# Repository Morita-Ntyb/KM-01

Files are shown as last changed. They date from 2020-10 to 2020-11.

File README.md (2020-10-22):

# KM-01
ミミがうごくヘッドホン

一つのミミにつきサーボ2つ(2軸) ヨーとピッチ方向で左右合計4軸を制御  
IMU(加速度センサ)の値を読み取り, サーボの角度に反映させる

# ハードウェア構成

## マイコン
Arduino UNO R3  
5V

## サーボ用PWM
PCA 9685 (秋月電子)  
https://akizukidenshi.com/catalog/g/gK-10350/  
16チャネル I2C接続 電源 5V サーボ用別系統5V

## IMU
SFE-SEN-13944 (スイッチサイエンス)  
https://www.switch-science.com/catalog/2881/
9Dof I2C接続 電源は3.3V

## サーボ(テスト用として)
FS90  
https://akizukidenshi.com/download/ds/feetech/fs90.pdf  
9gサーボ 180度

## バッテリー
Anker PowerCore+ 26800 PD  
PD対応(5V = 3A, 9V = 3A, 15V = 2A, 20V = 1.5A)　約100Wh  
Type-A - 2.1mm DCケーブルを自作する 

## 使用ライブラリ

PCA9685  https://akizukidenshi.com/catalog/g/gK-10350/  

SFE-SEN-13944 https://github.com/sparkfun/SparkFun_LSM9DS1_Arduino_Library  

## I2C アドレス設定
PCA 9685  0x40  
SFE-SEN-13944 0x6B 0x1E

# タスクリスト

* パーツを仮接続する ○

* パーツの動作試験用ソフトを完成させる I2Ctest ○

* 左側のミミだけ動かすソフトを完成させる proto_left ○
  * map 関数を使用しない実装 ○

* 両側のミミを動かすソフトを完成させる ○

10/02 完了　https://twitter.com/Morita_Ntyb/status/1311973911555309568

* 展示用のヘッドホン, フレーム部分のモデリング, プリント 組付け
  * フレームをFusion360で設計する ○
  * プリント ○
  * サーボ, IMUを取り付ける ○

10/20 完了

* ミミの形状を考える モデリング, プリント ○

* 配線する
  * Type-A - 2.1mm DCケーブルを作る ○

* 振動が起きる問題の修正
* y軸周りに回転させたとき下段サーボの動きが大きい問題の修正

* ジャイロセンサーの値をサーボの角度に反映させる
* I2Cについて調べる
* IMU(3.3V)とArduino(5V)間のI2Cにレベル変換回路を実装する https://www.switch-science.com/catalog/2396/  ○
* 電源スイッチを追加
* ロータリーエンコーダー(インクリメント)や可変抵抗でミミの角度を調整する機能を実装

以上

# ソフトウェア △

## I2Ctest ○

### サーボとIMUの動作を確認 I2C, ライブラリの使い方 ○
完成 確認

## proto_left ○

左側のみの動作

* IMUのデータに移動平均フィルタをかける ○
* 加速度センサのデータ(3次元ベクトル)から, ミミができるだけ垂直(+初期のオフセット)を維持するサーボの角度を計算する ○
    * 3変数関数を2つ(片側2軸)用意する ○

## exhibit ○

### proto_leftを基本に両方が動くようにする ○

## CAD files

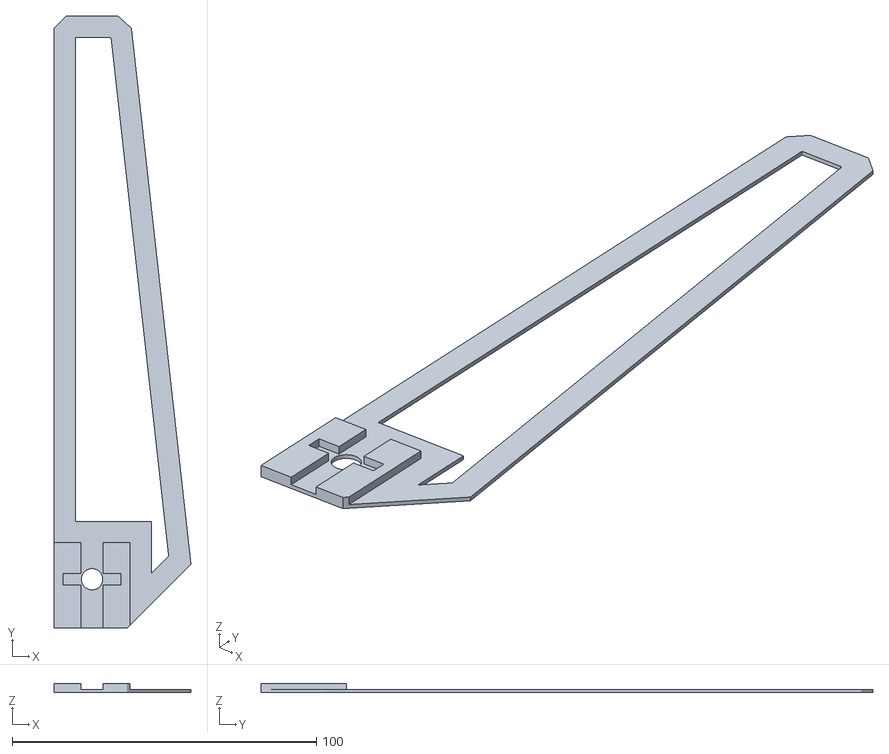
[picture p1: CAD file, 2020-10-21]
STLデータ/mimi.stl
45.0 x 201.0 x 3.00

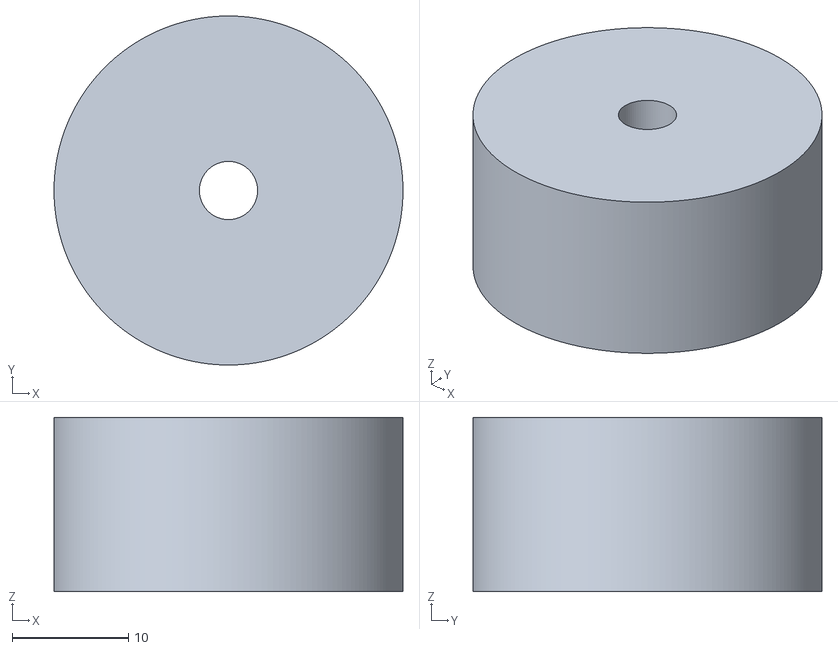
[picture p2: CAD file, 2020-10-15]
STLデータ/housing_2.stl
30.0 x 30.0 x 15.0

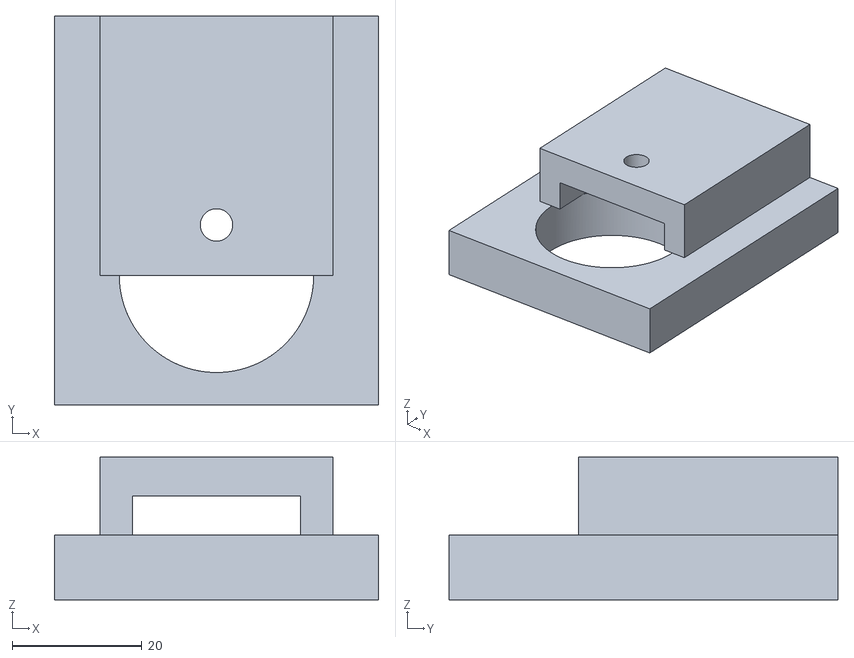
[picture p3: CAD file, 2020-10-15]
STLデータ/frame_housing_connection.stl
50.0 x 60.0 x 22.0

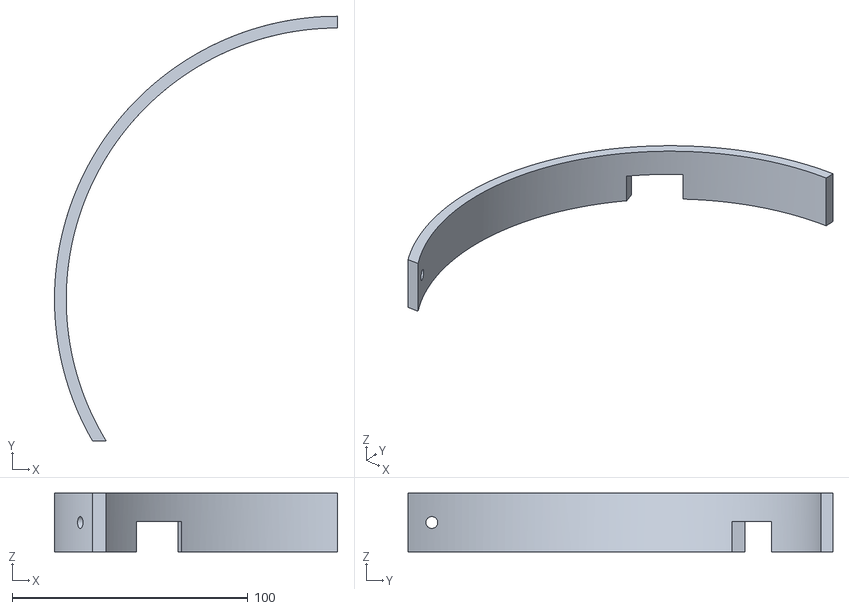
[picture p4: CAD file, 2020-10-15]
STLデータ/frame_side.stl
120.0 x 180.0 x 25.0

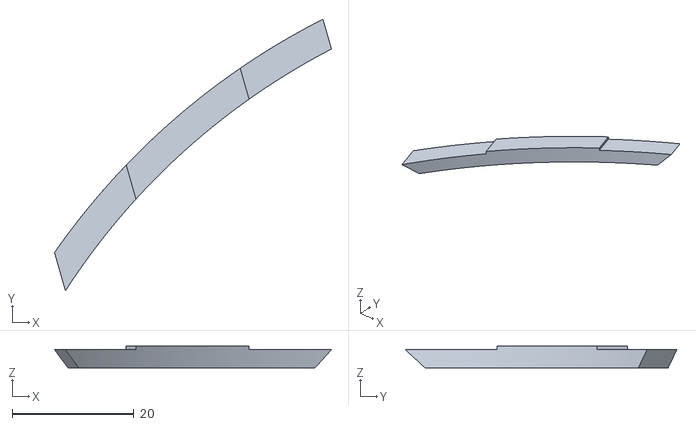
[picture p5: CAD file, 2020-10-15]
STLデータ/servo_side_support.stl
45.6 x 44.7 x 3.60

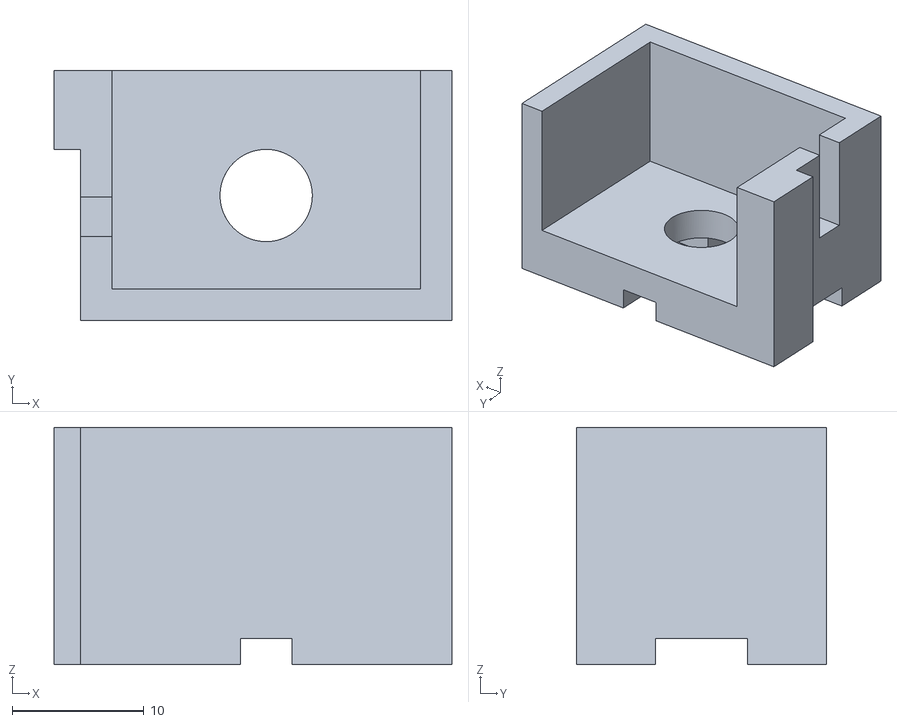
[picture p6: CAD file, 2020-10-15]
STLデータ/servo_bracket.stl
30.2 x 19.0 x 18.0

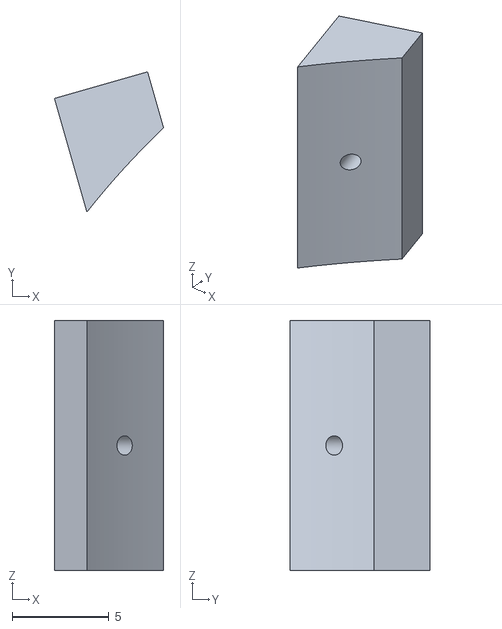
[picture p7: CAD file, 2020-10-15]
STLデータ/servo_spacer.stl
5.63 x 7.24 x 12.9

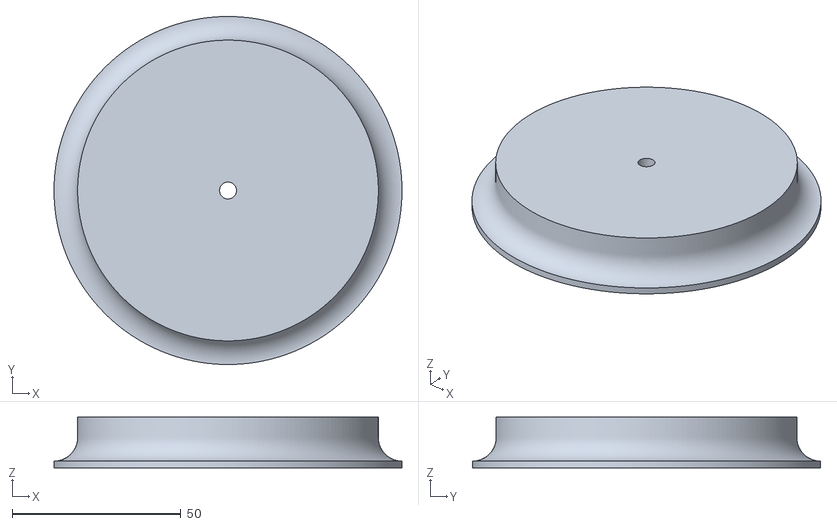
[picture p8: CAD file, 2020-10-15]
STLデータ/housing_1.stl
103.0 x 103.0 x 15.0

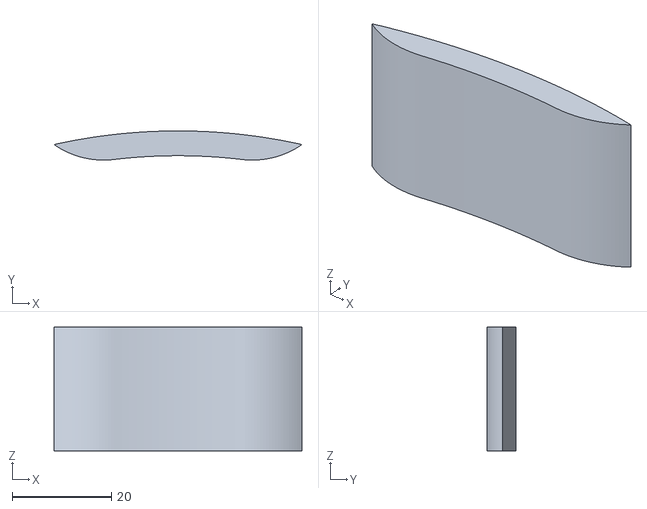
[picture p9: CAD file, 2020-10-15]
STLデータ/frame_top.stl
50.0 x 5.88 x 25.0

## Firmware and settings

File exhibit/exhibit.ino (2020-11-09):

#include <Wire.h>
#include <SPI.h>
#include <PCA9685.h> //https://akizukidenshi.com/catalog/g/gK-10350/
#include <SparkFunLSM9DS1.h> //https://github.com/sparkfun/SparkFun_LSM9DS1_Arduino_Library



PCA9685 pwm = PCA9685(0x40);//オブジェクト, アドレス指定

#define SERVOMIN 205 //1周期4096(ステップ)に対するサーボのパルス幅(ステップ)
#define SERVOMAX 983
#define PWMFREQ 50  //PWM周期

LSM9DS1 imu;  //LSM9DS1のオブジェクトを作成


//プロトタイプ宣言
void printAccel();
void shiftArray();
double average(const double*, int);

int serial_to_value(char*, int*);


void startUpSequence();

#define filterPoint 80  //移動平均フィルタのポイント数

//移動平均フィルタ用のバッファー
double xAccelBuffer[filterPoint];
double yAccelBuffer[filterPoint];
double zAccelBuffer[filterPoint];

static double a1 = -170.2564;
static double a2 = 195.3476;
static double a3 = -195.4023;
static double b1 = 0;
static double b2 = 195.3476;
static double b3 = 0;
static double c1 = 398.1524;


static double d1 = -170.2564;
static double d2 = 195.3476;
static double d3 = -195.4023;
static double e1 = 0;
static double e2 = 195.3476;
static double e3 = 0;
static double f1 = 398.1524;

static double g1 = 170.2564;
static double g2 = 195.3476;
static double g3 = 195.4023;
static double h1 = 0;
static double h2 = 195.3476;
static double h3 = 0;
static double i1 = 398.1524;

static double j1 = -170.2564;
static double j2 = 195.3476;
static double j3 = -195.4023;
static double k1 = 0;
static double k2 = 195.3476;
static double k3 = 0;
static double l1 = 398.1524;

char serial_string[16]; //シリアル通信 バッファ
int serial_int[4] = {0};
char gommy;
int j;

void setup()
{
  Serial.begin(9600);
  Serial.println("start setup...");

  
  pwm.begin();                   //初期設定
  pwm.setPWMFreq(PWMFREQ);       //PWM周期を設定

  Wire.begin();                  // I2Cを開く
  
  if (imu.begin() == false) // with no arguments, this uses default addresses (AG:0x6B, M:0x1E) and i2c port (Wire).
  {
    while (1);
  }
/*
  while(1)
  {
    gommy = Serial.read();
    Serial.print(gommy);
    if(gommy == 'F')
    {
      break;
    }
  }
  */
  
  //startUpSequence();

  Serial.println("end setup...");
}

void loop()
{
  if (Serial.available() > 16)
  { 
    for(j=0; j < 16; j++)
    {
      serial_string[j] = Serial.read();
    }
  }
  
  if ( imu.accelAvailable() )
  {
    imu.readAccel(); //IMUの値を更新
  }


  serial_to_value(serial_string, serial_int);

  for (j= 0; j< 3; j++)
  {
    serial_int[j] = map(serial_int[j], 0, 1024, 205, 985);
  }

  shiftArray(); //配列を一つ後ろにずらす

  //配列の先頭にセンサー値を代入する
  xAccelBuffer[0] = imu.calcAccel(imu.ax);
  yAccelBuffer[0] = imu.calcAccel(imu.ay);
  zAccelBuffer[0] = imu.calcAccel(imu.az);

  double xFAccel = average(xAccelBuffer, filterPoint);
  double yFAccel = average(yAccelBuffer, filterPoint);
  double zFAccel = average(zAccelBuffer, filterPoint);


  double servoDeg1 = a1*xFAccel*xFAccel*xFAccel + a2*xFAccel*xFAccel + a3*xFAccel
                   + b1*zFAccel*zFAccel*zFAccel + b2*zFAccel*zFAccel + b3*zFAccel + c1;
  double servoDeg2 = d1*yFAccel*yFAccel*yFAccel + d2*yFAccel*yFAccel + d3*yFAccel
                   + e1*zFAccel*zFAccel*zFAccel + e2*zFAccel*zFAccel + e3*zFAccel + f1;

  double servoDeg3 = g1*yFAccel*yFAccel*yFAccel + g2*yFAccel*yFAccel + g3*yFAccel
                   + h1*zFAccel*zFAccel*zFAccel + h2*zFAccel*zFAccel + h3*zFAccel + i1;
  double servoDeg4 = j1*xFAccel*xFAccel*xFAccel + j2*xFAccel*xFAccel + j3*xFAccel
                   + k1*zFAccel*zFAccel*zFAccel + k2*zFAccel*zFAccel + k3*zFAccel + l1;

    pwm.setPWM(0, 0, (int)((servoDeg1+0.5)/2.0));
    pwm.setPWM(2, 0, (int)((servoDeg2+0.5)/2.0));
    pwm.setPWM(13, 0, (int)((servoDeg3+0.5)/2.0));
    pwm.setPWM(15, 0, (int)((servoDeg4+0.5)/2.0));

  /*
  {
    pwm.setPWM(0, 0, serial_int[0]);
    pwm.setPWM(2, 0, serial_int[1]);
    pwm.setPWM(13, 0, serial_int[2]);
    pwm.setPWM(15, 0, serial_int[0]);
  }
  */
}

void shiftArray()
{


  for(int i=filterPoint -1 ; i > 0; --i)
  {
    xAccelBuffer[i] = xAccelBuffer[ i-1 ];
  }

  for(int i=filterPoint -1 ; i > 0; --i)
  {
    yAccelBuffer[i] = yAccelBuffer[ i-1 ];
  }

  for(int i=filterPoint -1 ; i > 0; --i)
  {
    zAccelBuffer[i] = zAccelBuffer[ i-1 ];
  }
  
}


double average(const double* array, int size)
{
    double result = 0;
    for (int i = 0; i < size; ++i) 
    {
        result += array[i];
    }
    return (result / (double)size ) ;
}

int serial_to_value(char* serial_string, int* target_array)
{
  int i=0;
  target_array[0] = ((int)serial_string[i]- 48 ) +( (int)serial_string[i+ 1]- 48 )* 10+ ((int)serial_string[i+ 2]- 48) * 100 + ((int)serial_string[i +3]- 48) * 1000 ;
  i += 4 ;  
  target_array[1] =( (int)serial_string[i]- 48 ) + ((int)serial_string[i+ 1]- 48 )* 10+ ((int)serial_string[i+ 2]- 48) * 100 + ((int)serial_string[i +3] - 48)* 1000 ;
  i += 4 ;  
  target_array[2] = ((int)serial_string[i]- 48 ) + ((int)serial_string[i+ 1] - 48) * 10+ ((int)serial_string[i+ 2]- 48 )* 100 + ((int)serial_string[i +3]- 48) * 1000 ;

  target_array[3] = serial_string[12] - 48;
}


/*
void startUpSequence()
{
    pwm.setPWM(1, 0, servoDeg1); //左 さげ
    delay(450);
    pwm.setPWM(0, 0, servoDeg2); //右 さげ
    delay(450);
    
    pwm.setPWM(3, 0, servoDeg3); //左 あげ
    delay(450);
    pwm.setPWM(2, 0, servoDeg4); //右 あげ
    delay(450);

    pwm.setPWM(2, 0, servoDeg4); //左 さげ
    pwm.setPWM(2, 0, servoDeg4); //右 さげ
    delay(240);
    pwm.setPWM(2, 0, servoDeg4); //左 あげ
    pwm.setPWM(2, 0, servoDeg4); //右 あげ

    delay(220);
    delay(500);

    pwm.setPWM(2, 0, servoDeg4); //左 あげ
    pwm.setPWM(2, 0, servoDeg4); //右 あげ
    
    delay(1100);
    

    //ゆっくり上げ(チルト) 1500ms

    delay(900);

    pwm.setPWM(2, 0, servoDeg4); //左 さげ
    pwm.setPWM(2, 0, servoDeg4); //右 さげ
    //140
}*/

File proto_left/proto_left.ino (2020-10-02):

 #include <Wire.h>
#include <SPI.h>
#include <PCA9685.h>
#include <SparkFunLSM9DS1.h>



PCA9685 pwm = PCA9685(0x40);//オブジェクト, アドレス指定

#define SERVOMIN 150 //1周期4096(ステップ)に対するサーボのパルス幅(ステップ)
#define SERVOMAX 500 //
#define PWMFREQ 50  //PWM周期

LSM9DS1 imu;  //LSM9DS1のオブジェクトを作成

#define PRINT_SPEED 50  //計算の周期 ms

static unsigned long lastPrint = 0;


//プロトタイプ宣言
void printAccel();
void shiftArray();
double average(const double*, int);



#define filterPoint 8  //移動平均フィルタのポイント数

//移動平均フィルタ用のバッファー
double xAccelBuffer[filterPoint];
double yAccelBuffer[filterPoint];
double zAccelBuffer[filterPoint];

static double a1 = 76.4952;
static double a2 = 105.8476 ;
static double a3 = 87.7931;
static double b1 = 0;
static double b2 = 105.8476 ;
static double b3 = 0;
static double c1 = 219.1524;

static double d1 = -76.4952;
static double d2 = 105.8476 ;
static double d3 = -87.7931;
static double e1 = 0;
static double e2 = 105.8476 ;
static double e3 = 0;
static double f1 = 219.1524;

void setup()
{
  pwm.begin();                   //初期設定
  pwm.setPWMFreq(PWMFREQ);       //PWM周期を設定

  Serial.begin(115200);         // テスト用途のシリアル通信

  Wire.begin();                  // I2Cを開く
  
  if (imu.begin() == false) // with no arguments, this uses default addresses (AG:0x6B, M:0x1E) and i2c port (Wire).
  {
    while (1);
  }

}

void loop()
{

  
  if ( imu.accelAvailable() )
  {
    imu.readAccel(); //IMUの値を更新
  }


 if ((lastPrint + PRINT_SPEED) < millis())
  {
    
    shiftArray(); //配列を一つ後ろにずらす

    //配列の先頭にセンサー値を代入する
    xAccelBuffer[0] = imu.calcAccel(imu.ax);
    yAccelBuffer[0] = imu.calcAccel(imu.ay);
    zAccelBuffer[0] = imu.calcAccel(imu.az);
    
    printAccel();
    
    double xFAccel = average(xAccelBuffer, filterPoint);
    double yFAccel = average(yAccelBuffer, filterPoint);
    double zFAccel = average(zAccelBuffer, filterPoint);

    Serial.print(xFAccel, 2);
    Serial.print(", ");
    Serial.print(yFAccel, 2);
    Serial.print(", ");
    Serial.print(zFAccel, 2);
    Serial.println();
    Serial.println();

    double servoDeg1 = a1*xFAccel*xFAccel*xFAccel + a2*xFAccel*xFAccel + a3*xFAccel
                     + b1*zFAccel*zFAccel*zFAccel + b2*zFAccel*zFAccel + b3*zFAccel + c1;
    double servoDeg2 = d1*yFAccel*yFAccel*yFAccel + d2*yFAccel*yFAccel + d3*yFAccel
                     + e1*zFAccel*zFAccel*zFAccel + e2*zFAccel*zFAccel + e3*zFAccel + f1;
   
    pwm.setPWM(1, 0, servoDeg1);
    pwm.setPWM(0, 0, servoDeg2);
    
    lastPrint = millis(); // 前回の時間を更新

  }


}

void shiftArray()
{
  
  
  for(int i=filterPoint -1 ; i > 0; --i)
  {
    xAccelBuffer[i] = xAccelBuffer[ i-1 ];
  }
  
  for(int i=filterPoint -1 ; i > 0; --i)
  {
    yAccelBuffer[i] = yAccelBuffer[ i-1 ];
  }
  
  for(int i=filterPoint -1 ; i > 0; --i)
  {
    zAccelBuffer[i] = zAccelBuffer[ i-1 ];
  }
  
}


double average(const double* array, int size)
{
    double result = 0;
    for (int i = 0; i < size; ++i) 
    {
        result += array[i];
    }
    return (result / (double)size ) ;
}
    

void printAccel()
{

  Serial.print(imu.calcAccel(imu.ax), 2);
  Serial.print(", ");
  Serial.print(imu.calcAccel(imu.ay), 2);
  Serial.print(", ");
  Serial.print(imu.calcAccel(imu.az), 2);
  Serial.print(", ");

}

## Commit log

2020-09-29 I2Cテスト
2020-09-29 proto_left作成
2020-09-29 使用ライブラリを追加
2020-09-29 ExponentialSmoothFunc.h を試す
2020-10-02 自作単純移動平均フィルタを試す
2020-10-02 移動平均フィルタを実装
2020-10-02 コメントを更新
2020-10-02 サーボのパルス範囲を仮設定
2020-10-02 ピッチ方向のサーボの動作
2020-10-02 直接パルス幅を計算
2020-10-02 下部のサーボ制御を追加
2020-10-02 フィルタの修正
2020-10-02 タスクを更新
2020-10-02 タスクの更新
2020-10-15 3Dデータを追加
    [frame_housing_connection.stl, frame_side.stl, frame_top.stl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]
2020-10-19 起動時の動作を追加
2020-10-21 ミミを軽量化
    [mimi.stl]
